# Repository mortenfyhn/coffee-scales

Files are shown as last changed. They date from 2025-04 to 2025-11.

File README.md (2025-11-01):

# coffee-scales



Kitchen scales, built for drip coffee brewing:

* 0.1 gram precision
* Very quick response
* Very quick tare
* Auto-starting brew timer
* Auto-off after 5 minutes

Current prototype looks something like this:

A PCB prototype in action

## Firmware

Setup:

1. [Install PlatformIO Core and shell commands](https://docs.platformio.org/en/latest/core/installation/index.html)
2. [Install Just](https://just.systems/man/en/packages.html)

Usage:

```sh
cd firmware
just --list
```

to list all recipes.

## Hardware

* Adafruit Feather 328P
* Load cell: 1 kg straight bar
* HX711 load cell amplifier
* Two 4-digit 7-segment displays with TM1637 drivers
* LiPo battery (1200 mAh)
* Push button for taring

Connection diagram

## Development and debugging

Log raw data to CSV with the logging recipe. Then process the data with `firmware/logs/process.m`. Look at the processed CSV in e.g. PlotJuggler.

Here's the state diagram:



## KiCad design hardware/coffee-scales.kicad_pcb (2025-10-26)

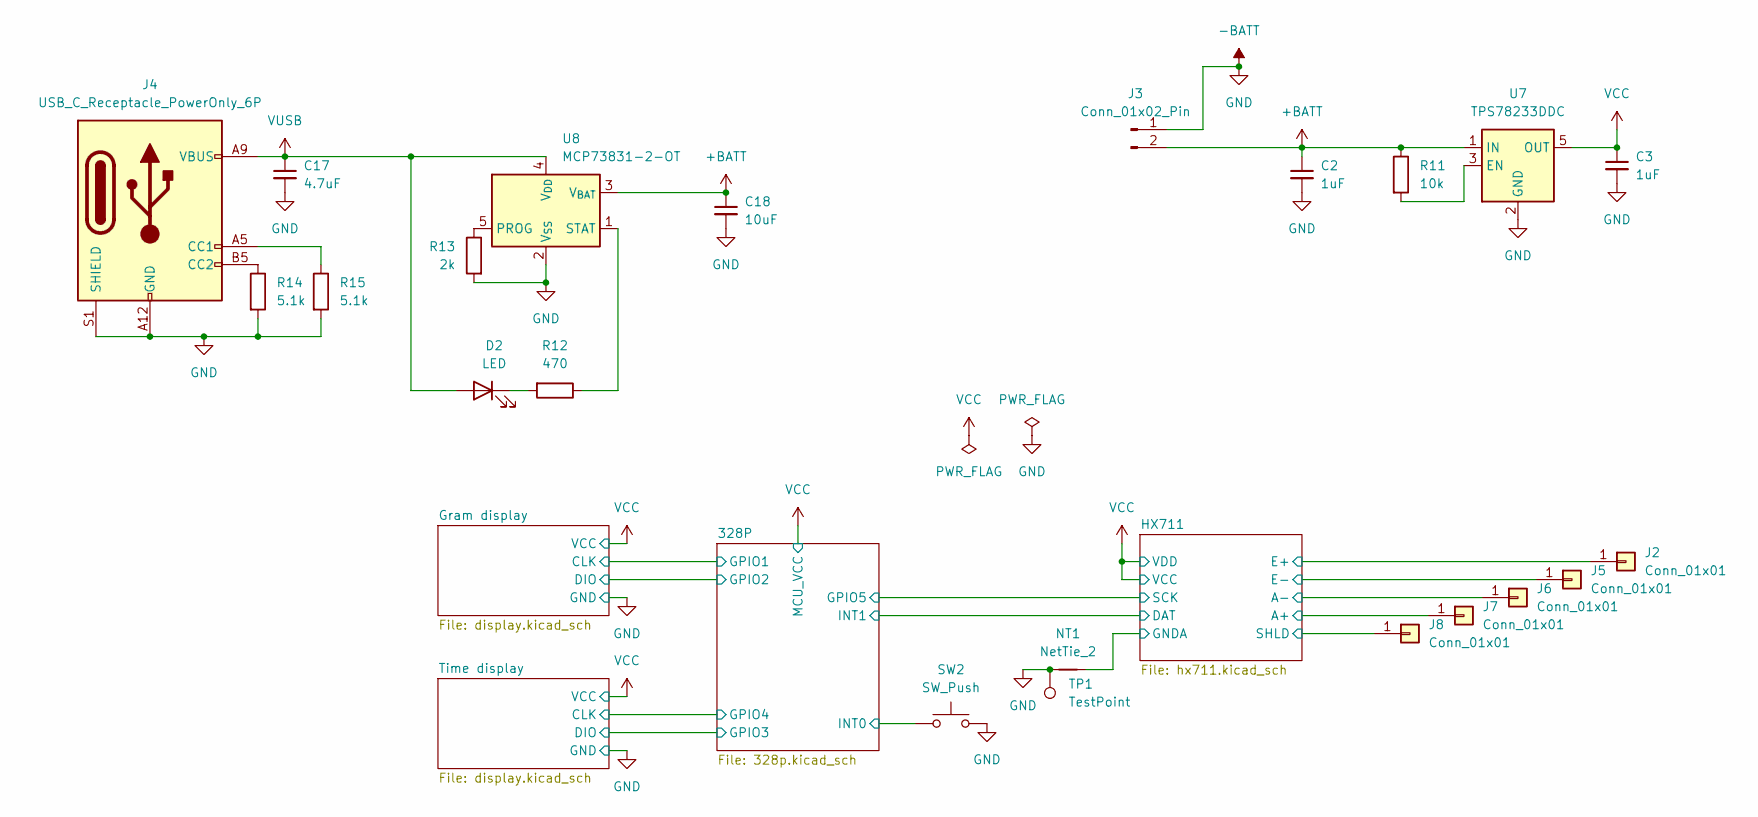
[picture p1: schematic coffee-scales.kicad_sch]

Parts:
C2, C3: 1uF; C_0603_1608Metric
C17: 4.7uF; C_0805_2012Metric
C18: 10uF; C_0805_2012Metric
D2: LED; LED_0805_2012Metric
J2, J5, J6, J7, J8: Conn_01x01; TestPoint_Pad_D1.5mm
J3: Conn_01x02_Pin; JST_PH_S2B-PH-SM4-TB_1x02-1MP_P2.00mm_Horizontal
J4: USB_C_Receptacle_PowerOnly_6P; USB_C_Receptacle_GCT_USB4125-xx-x-0190_6P_TopMnt_Horizontal
NT1: NetTie_2; NetTie-2_SMD_Pad0.5mm
R11: 10k; R_0603_1608Metric
R12: 470; R_0603_1608Metric
R13: 2k; LED_0603_1608Metric
R14, R15: 5.1k; R_0603_1608Metric
SW2: SW_Push; SW_PUSH-12mm
TP1: TestPoint; TestPoint_THTPad_D1.0mm_Drill0.5mm
U7: TPS78233DDC; SOT-23-5
U8: MCP73831-2-OT; SOT-23-5

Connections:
+BATT: C2.1, C18.1, J3.2, R11.1, U7.1 (IN), U8.3 (V_{BAT})
-BATT: C2.2, C3.2, C17.2, C18.2, J3.1, J4.A12 (GND), J4.B12 (GND), J4.S1 (SHIELD), NT1.2, R13.2, R14.2, R15.2, SW2.2, TP1.1, U7.2 (GND), U7.4 (GND), U8.2 (V_{SS}); also elsewhere on the board
/328P/INT0: SW2.1; also elsewhere on the board
/HX711/A+: J7.1; also elsewhere on the board
/HX711/A-: J6.1; also elsewhere on the board
/HX711/E+: J2.1; also elsewhere on the board
GNDA: J5.1, J8.1, NT1.1; also elsewhere on the board
unnamed: D2.1 (K), R12.2
unnamed: J4.A5 (CC1), R15.1
unnamed: J4.B5 (CC2), R14.1
unnamed: R11.2, U7.3 (EN)
unnamed: R13.1, U8.5 (PROG)
unnamed: R12.1, U8.1 (STAT)
VCC: C3.1, U7.5 (OUT); also elsewhere on the board
VUSB: C17.1, D2.2 (A), J4.A9 (VBUS), J4.B9 (VBUS), U8.4 (V_{DD})

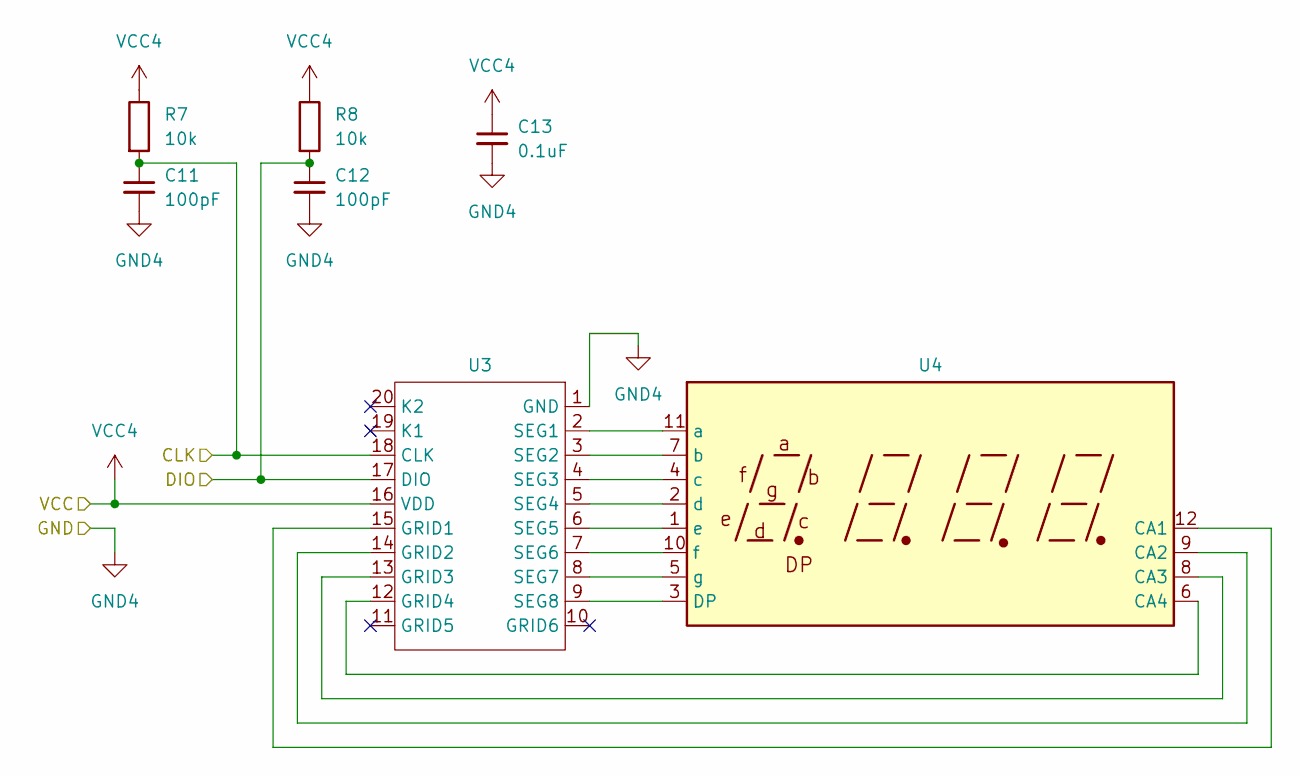
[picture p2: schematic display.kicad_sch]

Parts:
C11, C12: 100pF; C_0603_1608Metric
C13: 0.1uF; C_0603_1608Metric
R7, R8: 10k; R_0603_1608Metric
U3: SOP-20_7.5x12.8mm_P1.27mm_3d
U4: 7_segment

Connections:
-BATT: C11.2, C12.2, C13.2, U3.1 (GND); also elsewhere on the board
/328P/GPIO1: C11.1, R7.2, U3.18 (CLK); also elsewhere on the board
/328P/GPIO2: C12.1, R8.2, U3.17 (DIO); also elsewhere on the board
unnamed: U3.15 (GRID1), U4.12 (CA1)
unnamed: U3.14 (GRID2), U4.9 (CA2)
unnamed: U3.13 (GRID3), U4.8 (CA3)
unnamed: U3.12 (GRID4), U4.6 (CA4)
unnamed: U3.2 (SEG1), U4.11 (a)
unnamed: U3.3 (SEG2), U4.7 (b)
unnamed: U3.4 (SEG3), U4.4 (c)
unnamed: U3.5 (SEG4), U4.2 (d)
unnamed: U3.6 (SEG5), U4.1 (e)
unnamed: U3.7 (SEG6), U4.10 (f)
unnamed: U3.8 (SEG7), U4.5 (g)
unnamed: U3.9 (SEG8), U4.3 (DP)
VCC: C13.1, R7.1, R8.1, U3.16 (VDD); also elsewhere on the board

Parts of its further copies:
C14, C15: 100pF; C_0603_1608Metric
C16: 0.1uF; C_0603_1608Metric
R9, R10: 10k; R_0603_1608Metric
U5: SOP-20_7.5x12.8mm_P1.27mm_3d
U6: 7_segment

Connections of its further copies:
-BATT: C14.2, C15.2, C16.2, U5.1 (GND); also elsewhere on the board
/328P/GPIO3: C14.1, R10.2, U5.17 (DIO); also elsewhere on the board
/328P/GPIO4: C15.1, R9.2, U5.18 (CLK); also elsewhere on the board
unnamed: U5.15 (GRID1), U6.12 (CA1)
unnamed: U5.14 (GRID2), U6.9 (CA2)
unnamed: U5.13 (GRID3), U6.8 (CA3)
unnamed: U5.12 (GRID4), U6.6 (CA4)
unnamed: U5.2 (SEG1), U6.11 (a)
unnamed: U5.3 (SEG2), U6.7 (b)
unnamed: U5.4 (SEG3), U6.4 (c)
unnamed: U5.5 (SEG4), U6.2 (d)
unnamed: U5.6 (SEG5), U6.1 (e)
unnamed: U5.7 (SEG6), U6.10 (f)
unnamed: U5.8 (SEG7), U6.5 (g)
unnamed: U5.9 (SEG8), U6.3 (DP)
VCC: C16.1, R9.1, R10.1, U5.16 (VDD); also elsewhere on the board

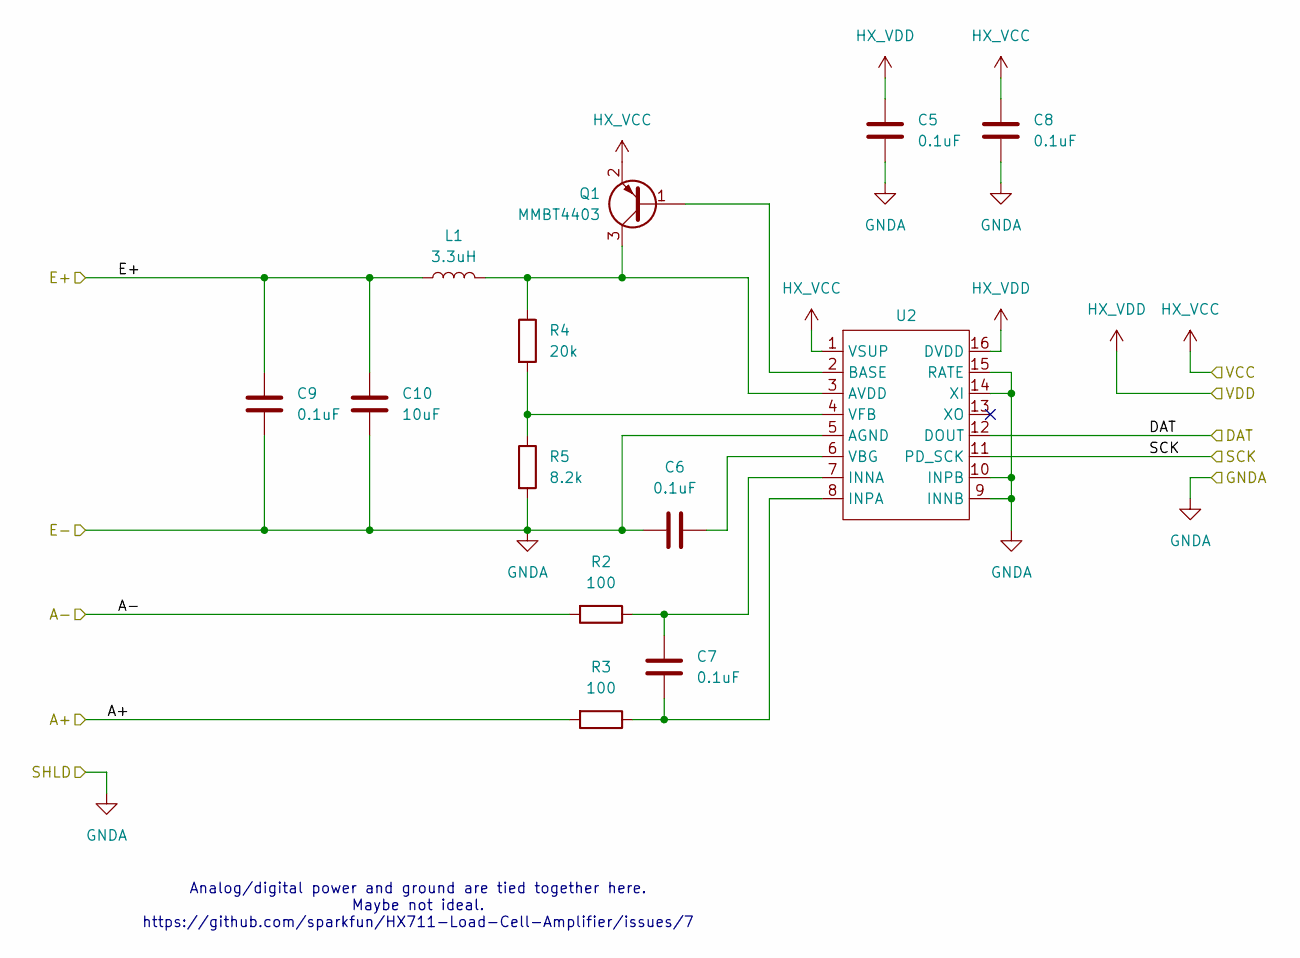
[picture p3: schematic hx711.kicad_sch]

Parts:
C5, C6, C7, C8, C9: 0.1uF; C_0603_1608Metric
C10: 10uF; C_1210_3225Metric
L1: 3.3uH; L_0805_2012Metric
Q1: MMBT4403; TSOT-23
R2, R3: 100; R_0603_1608Metric
R4: 20k; R_0603_1608Metric
R5: 8.2k; R_0603_1608Metric
U2: SOP-16_3.9x9.9mm_P1.27mm

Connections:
/HX711/A+: R3.2; also elsewhere on the board
/HX711/A-: R2.2; also elsewhere on the board
/HX711/DAT: U2.12 (DOUT); also elsewhere on the board
/HX711/E+: C9.1, C10.1, L1.1; also elsewhere on the board
/HX711/SCK: U2.11 (PD_SCK); also elsewhere on the board
GNDA: C5.2, C6.1, C8.2, C9.2, C10.2, R5.2, U2.5 (AGND), U2.9 (INNB), U2.10 (INPB), U2.14 (XI), U2.15 (RATE); also elsewhere on the board
unnamed: Q1.1 (B), U2.2 (BASE)
unnamed: L1.2, Q1.3 (C), R4.1, U2.3 (AVDD)
unnamed: C7.1, R2.1, U2.7 (INNA)
unnamed: C7.2, R3.1, U2.8 (INPA)
unnamed: C6.2, U2.6 (VBG)
unnamed: R4.2, R5.1, U2.4 (VFB)
VCC: C5.1, C8.1, Q1.2 (E), U2.1 (VSUP), U2.16 (DVDD); also elsewhere on the board

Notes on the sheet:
Analog/digital power and ground are tied together here. Maybe not ideal. https://github.com/sparkfun/HX711-Load-Cell-Amplifier/issues/7

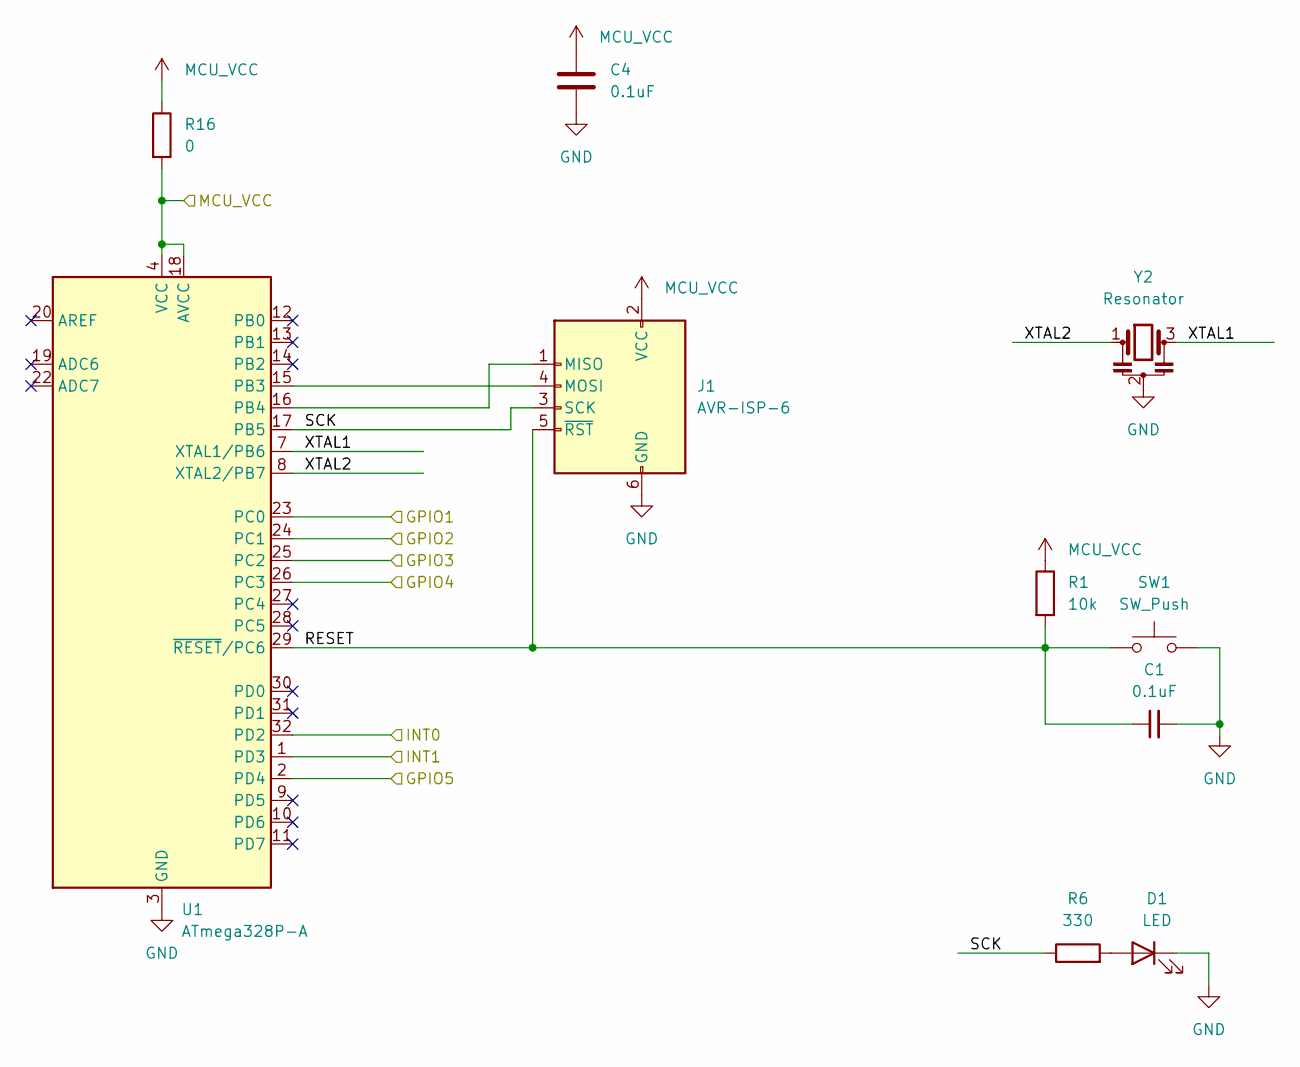
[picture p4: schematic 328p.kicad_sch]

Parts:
C1, C4: 0.1uF; C_0603_1608Metric
D1: LED; LED_0805_2012Metric
J1: AVR-ISP-6; PinHeader_2x03_P2.54mm_Horizontal
R1: 10k; R_0603_1608Metric
R6: 330; R_0603_1608Metric
R16: 0; R_1206_3216Metric_Pad1.30x1.75mm_HandSolder
SW1: SW_Push; SW_Push_1P1T_NO_CK_KMR2
U1: ATmega328P-A; TQFP-32_7x7mm_P0.8mm
Y2: Resonator; Resonator_SMD_Murata_CSTxExxV-3Pin_3.0x1.1mm

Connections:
-BATT: C1.2, C4.2, D1.1 (K), J1.6 (GND), SW1.2, U1.3 (GND), U1.5 (GND), U1.21 (GND), Y2.2; also elsewhere on the board
/328P/GPIO1: U1.23 (PC0); also elsewhere on the board
/328P/GPIO2: U1.24 (PC1); also elsewhere on the board
/328P/GPIO3: U1.25 (PC2); also elsewhere on the board
/328P/GPIO4: U1.26 (PC3); also elsewhere on the board
/328P/INT0: U1.32 (PD2); also elsewhere on the board
/328P/RESET: C1.1, J1.5 (~RST), R1.2, SW1.1, U1.29 (~RESET/PC6)
/328P/SCK: J1.3 (SCK), R6.1, U1.17 (PB5)
/328P/XTAL1: U1.7 (XTAL1/PB6), Y2.3
/328P/XTAL2: U1.8 (XTAL2/PB7), Y2.1
/HX711/DAT: U1.1 (PD3); also elsewhere on the board
/HX711/SCK: U1.2 (PD4); also elsewhere on the board
unnamed: D1.2 (A), R6.2
unnamed: J1.1 (MISO), U1.16 (PB4)
unnamed: J1.4 (MOSI), U1.15 (PB3)
VCC: C4.1, J1.2 (VCC), R1.1, R16.1, R16.2, U1.4 (VCC), U1.6 (VCC), U1.18 (AVCC); also elsewhere on the board

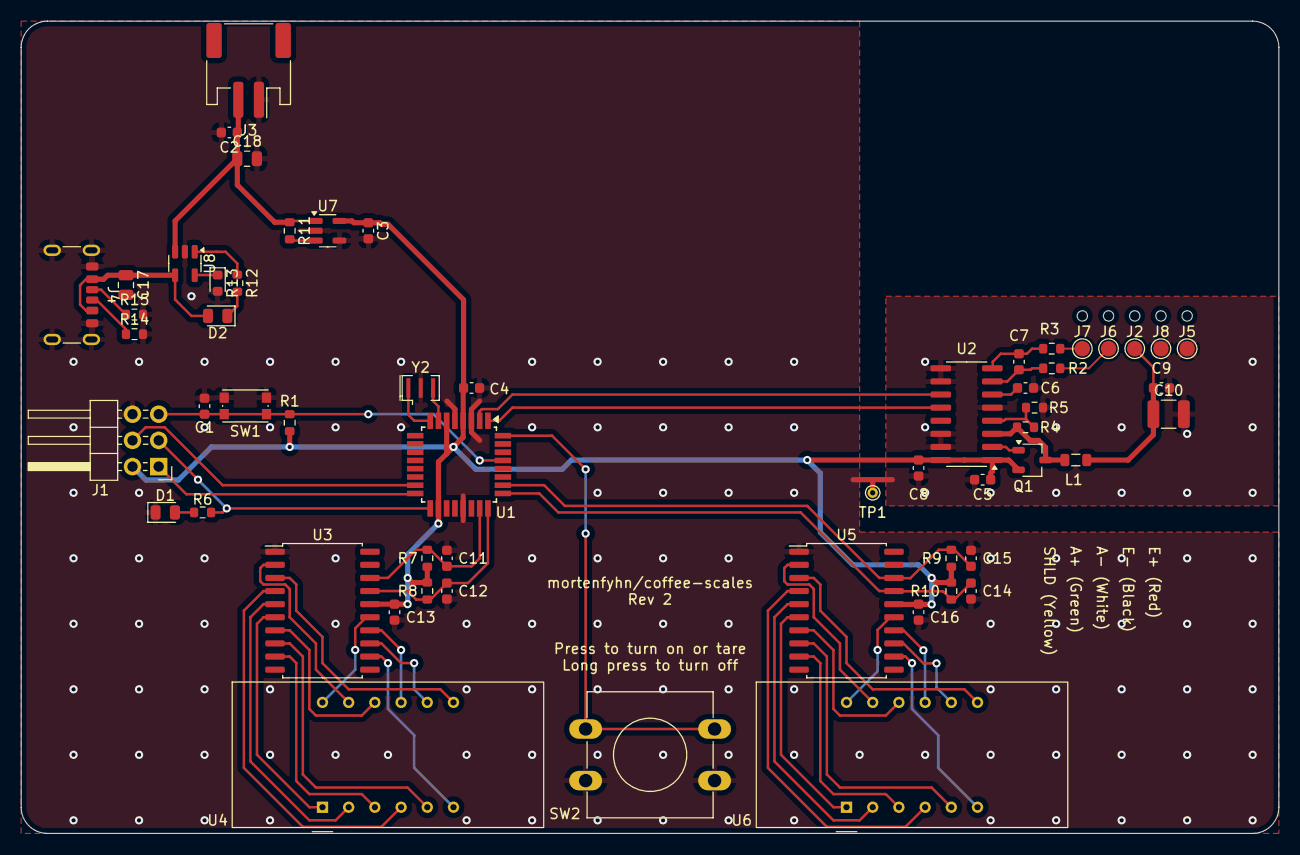
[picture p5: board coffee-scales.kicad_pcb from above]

Board: 2 copper layers, 121.9 x 78.7 mm, 58 parts (0 on the bottom side), 58 nets.

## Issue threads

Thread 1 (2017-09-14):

Add support for negative weight

mortenfyhn, 2017-09-14:
The scales cannot currently display negative numbers on the 7-segment display. Fix it.

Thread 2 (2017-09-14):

Reduce measurement jitter

mortenfyhn, 2017-09-14:
The measurement sometimes jitters between adjacent tenth of gram values. Need better measurement filtering to avoid this.

mortenfyhn, 2017-09-14:
Achieved using hysteresis (commit 2903dbe).

Closed 2017-09-14.

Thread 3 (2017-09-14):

Add tare button

mortenfyhn, 2017-09-14:
Add a physical tare button, and implement it in software. Should probably just be a simple momentary button. Even I can understand the circuit:

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
---
* [ ] Choose a button that fits and feels nice.
* [ ] Integrate it.

mortenfyhn, 2020-11-28:
Also do #14 as part of this.

mortenfyhn, 2023-05-01:
Closed by 229d202

Closed 2023-05-01.

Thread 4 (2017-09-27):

Question: What sort of load cell did you use for this project?

brianbowden, 2017-09-27:

mortenfyhn, 2017-09-28:
I use a cheap 1 kg load cell that came with an HX711 load cell amplifier breakout board, similar to this: https://i.imgur.com/7wJsbHm.jpg. Five dollars on eBay.

Closed 2017-09-28.

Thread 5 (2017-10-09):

Automatic display brightness

mortenfyhn, 2017-10-09:
I'll just use a photoresistor. Keep it simple. With the random ldr I have, I measure approx
* 1 ohm (raw 633) outside on a bright but overcast day (should give 100 % brightness)
* 2k ohm (raw 540) in a bright room (should give 100 % brightness)
* 10k (raw 350) ohm in a medium bright room (should probably give less than 100 % brightness)
* above 2M ohm (raw 36) in a really dark room with no lights on (should give minimum brightness)

So it seems that with a circuit like `[3v3]---[ldr]---[Vmeas]---[10K]---[gnd]` and the ldr I have, a good starting point is: max brightness above `Vmeas = 2.44 V (500 raw analog with Vref = 5v)` and minimum brightness below `Vmeas = 0.73 V (150 raw analog)`.

---
* [x] Get suitable photoresistor.
* [x] Figure out suitable fixed series resistor. --> 10k
* [ ] Test separately (write a small program that outputs 0-100 depending on ambient light).
* [ ] Integrate with everything else.

Closed 2020-10-31.

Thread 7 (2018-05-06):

Choose and order new computer

mortenfyhn, 2018-05-06:
Adafruit feathers seem nice because they have the charging circuit integrated:
* [Feather 328P](https://www.adafruit.com/product/3458): same mcu as the old arduino
* [Feather M0](https://www.adafruit.com/product/2772): more power and a bit more proto space
---
* [x] Decide which to order --> M0 lol
* [x] Order comp
* [x] Order battery

mortenfyhn, 2018-07-18:
Done!

Closed 2018-07-18.

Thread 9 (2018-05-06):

Make display modules

mortenfyhn, 2018-05-06:
The old display modules are too big. Gonna develop new ones that
* have a PCB that is the same height as the 7-segment itself,
* are the same size (0.56") or smaller, and
* probably use the HT16K33 instead of TM1637 (HT seems to require fewer external components).
---
* [ ] Make schematic.
* [ ] Make layout.
* [ ] Order from osh park or something.
* [ ] Order 7-segments.
* [x] Order HT16K33s (can get them [here](https://lcsc.com/product-detail/LED-Drivers_HT16K33_C87502.html))
* [ ] Assemble and verify.

Closed 2020-10-31.

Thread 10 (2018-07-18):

Don't reset timer when removing weight

mortenfyhn, 2018-07-18:

Closed 2018-07-20.

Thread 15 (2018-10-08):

Successive tare computation

mortenfyhn, 2018-10-08:
The current taring just reads a raw value _n_ times and sets the offset equal to the average of the readings. What if I instead take a single reading and set the offset repeatedly until for instance the change in offset is very small. Then taring a) might go faster and b) won't fail if it happens while the applied weight changes.

Closed 2020-10-31.

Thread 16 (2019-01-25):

Sometimes displays wrong weight

mortenfyhn, 2019-01-25:
Seems to happen after it's been used with a particularly heavy item. The weight starts to alternate between 1156 and 1565 at something like 3 Hz. The timer still runs fine.

Closed 2020-10-31.

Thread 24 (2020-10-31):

Filtering is broken

mortenfyhn, 2020-10-31:
The weight reading is very unstable.

mortenfyhn, 2020-11-01:
I printed the raw value going into the filter and the filtered value coming out, and they are the same:
```
-0.07 -0.07
0.28 0.28
1.18 1.18
1.56 1.56
1.53 1.56
1.13 1.13
2.10 2.10
2.95 2.95
1.96 1.96
1.11 1.11
```

mortenfyhn, 2020-11-01:
Seems to be caused by the filter always reporting "not in steady state", in which case it just returns the most recent value. I think the raw signal from the load cell amplifier is noisier than it used to be, for whatever reason.

mortenfyhn, 2020-11-01:
"Fixed" by using another HX711 breakout board. Maybe the bad one used 80 Hz higher noise sampling, and the good one 10 Hz, I think I read about that in the datasheet.

Closed 2020-11-01.

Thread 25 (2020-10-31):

Refactor gramsDisplay with tests

mortenfyhn, 2020-10-31:
A good opportunity to try out doctest

* [x] Get any test example running
* [x] Share dependency specification

mortenfyhn, 2020-11-02:
Possible to do this?

* Convert float to string, with exactly one decimal place
* if 4 chars or less (excluding decimal separator dot)
  * return result
* try convert with no decimal place
* if 4 chars or less
  * return result
* print error

mortenfyhn, 2020-11-28:
Done! 6146b00

Closed 2020-11-28.

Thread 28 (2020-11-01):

Set up static analysis

mortenfyhn, 2020-11-01:
Clang tidy probably.

* [ ] Run and fix current clang tidy errors.
* [ ] Integrate with CI.

Closed 2023-04-30.

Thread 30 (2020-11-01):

Design new PCB

mortenfyhn, 2020-11-01:
Gotta decide what to include and what to skip.

sindrehan, 2020-11-20:
Let me know if you want a review of/help with the PCB. Are you using KiCad?

mortenfyhn, 2020-11-20:
That'd be great! @yttersian is helping out with PCB design, maybe we can all collaborate? I don't remember what he suggested using. @Slattsveen has also offered to help with making an enclosure / machining.

Roughly, the plan for the first pcb revision is

* Still use the full arduino nano 328, and just solder its pin headers to the pcb.
* Get rid of the seven segment display breakouts, get the TM1637 + display circuits onto our board
* Add batteries + battery circuit (rechargeable, or disposable if they last long enough)
* Add a tare button
* Either create a drop-in slot for the HX711 breakout, or re-implement that directly on the board

Closed 2023-04-30.

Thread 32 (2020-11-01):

Consistent 0.0 after boot

mortenfyhn, 2020-11-01:
Seems that the HX711 outputs slightly wrong data first. Maybe we can adjust the tare function to wait for it to settle.

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

mortenfyhn, 2020-11-02:
Maybe we can cheat by having a small deadband around zero.

mortenfyhn, 2020-11-17:
Kinda works now.

mortenfyhn, 2023-05-11:
Plan:

* [ ] Get a log of data from a typical brew
* [ ] Then try different filtering techniques until flat parts are completely flat and changing parts change with minimal delay
* [ ] Discretize the output to 0.1 g intervals to check jitter

mortenfyhn, 2023-05-31:
Right now it's __almost__ consistent 0.0 after tare. The fix must be to tare based on an averaged value instead of based on just one reading.

mortenfyhn, 2023-05-31:
Took another startup log, and it seems the first 5-ish measurements (0.3 ish seconds) are off, before it settles.

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

Closed 2023-12-10.

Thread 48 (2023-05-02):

Mount everything on perfboard

mortenfyhn, 2023-05-02:
* [x] Need to get a switch (a nice toggle)
* [ ] Figure out layout
* [ ] Need larger board?
* [ ] Solder it up!

mortenfyhn, 2023-05-03:
https://www.taydaelectronics.com/sub-mini-toggle-switch-2m-series-spst-off-on.html

mortenfyhn, 2023-05-03:
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

Closed 2023-12-15.

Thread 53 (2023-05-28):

Log raw data for filter testing

mortenfyhn, 2023-05-28:

mortenfyhn, 2023-05-28:
Here is some:

[log.txt](https://github.com/mortenfyhn/coffee-scales/files/11584877/log.txt)

This is from actually brewing a cup of coffee:

* 12 g coffee
* 200 g water
* Using Hoffman's new V60 method: Pour 1/5th of the water at 0:00, 0:45, 1:10, 1:30, and 1:50.
* Swirl after first pour and after final pour.
* Done after roughly 3:30 (220k in the log)
* Left to sit until 5:00

The log format is just `MILLIS DATA` (space separated) with milliseconds since device boot, and DATA being raw data from the load cell amplifier. The input to the filter is (DATA - offset) / scale, where the scale is 1874.f and the offset is whatever makes it zero in the beginning.

Closed 2023-05-28.

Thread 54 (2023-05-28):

Design a better filter

mortenfyhn, 2023-05-28:
Use the logged data I have.

Spec / goal:
* Zero jitter during steady state
* Very quick response when adding weight
* No overshoot

Maybe bias estimation? In the log data, after finishing the pour, the data falls from 200.45 to 198.98 over approx 90 seconds. But maybe that's just evaporation!?

* [ ] Take another log, maybe 10 minutes, with nothing on the scales.

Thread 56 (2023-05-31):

Low battery indicator

mortenfyhn, 2023-05-31:

mortenfyhn, 2023-05-31:
Fixed!

Closed 2023-05-31.

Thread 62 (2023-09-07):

Make it legible in sunlight

mortenfyhn, 2023-09-07:
The Acaia Pearl has it so why not I?

mortenfyhn, 2023-12-10:
Looks like just wiring the displays to VBAT instead of 3V3 helps a lot if the battery is fully charged. So that's something.

mortenfyhn, 2023-12-15:
Sort of fixed by hooking up the display's vcc line to VBAT instead of the feather's 3v3 output, which means they get something like 3.6 to 4.2 volts, depending on battery charge.

Closed 2023-12-15.

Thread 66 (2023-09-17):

Proper solution for on/off

mortenfyhn, 2023-09-17:
Can I wake it with the tare button, and have it auto-off?

mortenfyhn, 2023-12-15:
I've got it.

* AVR deep sleep after 5 min inactivity
* Wake on interrupt (the tare button)
* Physically cut of the power leds underneath the display modules
* Set the HX711 to power down before entering sleep mode

Fixed by a7e02a1

Closed 2023-12-15.

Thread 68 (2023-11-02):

Flash low batt lamp instead of just turn it on

mortenfyhn, 2023-11-02:
And actually test it...

mortenfyhn, 2023-12-09:
It seems to work! I didn't measure the voltages, but it turned red recently and charging it overnight made it no longer red : )

Closed 2023-12-15.

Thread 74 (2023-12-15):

Minimize power consumption

mortenfyhn, 2023-12-15:
The entire device (measured on battery input at 4.1 V):

* Active: 50-60 mA
* Sleep: 0.5 mA @ 4.1 V = 2.05 mW

The load cell + amplifier (measured on 3.3 V line):

* Active: 10 mA
* Sleep: 0.0 uA

The displays (measured on battery line at 4.1 V):

* Active: 50 mA
* Sleep: 190 uA @ 4.1 V = 0.78 mW

The push button uses a small amount of power when pressed and nothing when not pressed.

So where is the remaining 1.27 mW going??

Standby: 0.5 mA gives around 100 days.
Usage: 50 mA gives around 24 hours.
So if I use it, say, twice a day, 5 min brew + 5 min timeout each time, that's 20 minutes usage per day + 1420 minutes standby. That's 16.7 mAh (usage) + 11.8 mAh (standby) = 28.5 mAh -> 42 days, assuming 1200 mAh battery.
Very back of the envelope.

mortenfyhn, 2023-12-31:
* [ ] Do the displays use more power in standby because they're hooked up to the battery line instead of the 3v3 line?

mortenfyhn, 2024-01-03:
The TM1637 driver has a parameter `bool on`. I wonder if the power consumption is changed by this, when all segments are off:

https://github.com/avishorp/TM1637/blob/82214be06742bf187fab4f29aaabb64c289eaae0/TM1637Display.h#L49-L51

mortenfyhn, 2024-12-15:
Maybe switch to an ATtiny1614 eventually

mortenfyhn, 2024-12-29:
Some profiling of the active state loop of today's version (235c0ac):

| task | description            | approx. duration (us) |
|------|------------------------|-|
| 1    | check for button press | 8 |
| 2    | wait for hx711 ready   | (irrelevant) |
| 3    | read from hx711        | 800 |
| 4    | compute grams [1]      | 80 |
| 5    | add value to filter    | 80 |
| 6    | get filtered value     | 1000 |
| 7    | compute hysteresis     | 60 |
| 8    | format scale segments  | 450 |
| 9    | set scale segments     | **23 150** |
| 10   | update timer display   | **34 250** |
| 11   | check for steady state | 700 |
| 12   | check activity timeout | 8 |

[1]:

https://github.com/mortenfyhn/coffee-scales/blob/235c0ac4d8fc71c11c5e866e6baab060c1ca74b6/firmware/src/main.cpp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

mortenfyhn, 2024-12-29:
However with a different 7segment library:

| task | description            | approx. duration (us) |
|------|------------------------|-|
| 1    | check for button press | 8 |
| 2    | wait for hx711 ready   | - |
| 3    | read from hx711        | 746 |
| 4    | compute grams          | 76 |
| 5    | add value to filter    | 70 |
| 6    | get filtered value     | 963 |
| 7    | compute hysteresis     | 53 |
| 8    | format scale segments  | 481 |
| 9    | set scale segments     | 1015 |
| 10   | update timer display   | 1503 |
| 11   | check for steady state | 700 |
| 12   | check activity timeout | 14 |

mortenfyhn, 2024-12-29:
So that means we for each 100 ms iteration (HX711 is configured for 10 Hz output), we work for 5-6 ms, and then do nothing (busy loop) for the remainder.

Note that the above is all with `-Os`.

**Next:**

* [ ] Actually implement sleeping and interrupt wake for when the HX711 is ready
* [ ] Try to squeeze even more speed improvements?

mortenfyhn, 2024-12-29:
Anyway come back to this after standalone MCU PCB without arduino board.

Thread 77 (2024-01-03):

Disable or fix low battery light

mortenfyhn, 2024-01-03:
It seems to be poorly calibrated, and if I charge it without power cycling it won't turn off when the battery is full after charging.

Closed 2024-01-03.

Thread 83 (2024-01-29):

Long press to shut down

mortenfyhn, 2024-01-29:
I've long resisted having another shutdown button or method than just "wait for it to time out".

But a long press might be good. Then anyone who wants to be able to immediately shut down can, without this affecting the UI/UX for everyone else.

mortenfyhn, 2024-02-23:
* same logic as today's tare?
* start taring immediately even if doing a long press
* check the button class state for each iteration (no interrupt here)
* class logic can then determine if button has been pressed at every checkpoint for the last X duration

mortenfyhn, 2024-04-08:
I have something that kind of works now. But:

* [ ] after the button is held down and the scales sleep, the interrupt must become a no-op for a little while

otherwise letting go of the button very easily wakes it right up again, because of bouncing.

Closed 2024-05-12.

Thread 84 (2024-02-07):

Manual sleep before HX711 read?

mortenfyhn, 2024-02-07:
If the read is a busy loop, maybe that's wasting energy and I instead can sleep until it's ready.

mortenfyhn, 2024-05-12:
It does seem to be a busy loop, the HX711 driver just does "while not ready, delay(0)".

I should instead try to estimate when it will be ready and do some kind of proper low power sleep until then.

I should also consider just hooking up an interrupt to the DOUT pin, which is what "is ready" actually checks: When DOUT goes low, it means data is ready for reading.

And I should do some timing again to see which parts of the program take how much time.

And then consider optimizing the rest of the code.

mortenfyhn, 2024-12-29:
Subset of #74

Closed 2024-12-29.

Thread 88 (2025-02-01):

Long press does not always work

mortenfyhn, 2025-02-01:
Sometimes it just randomly does not work (pressing the button does not cause sleep). And during taring it never works. It should always work.

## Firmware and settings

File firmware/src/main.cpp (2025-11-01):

#include "button.h"
#include "config.h"
#include "serial.h"
#include <Arduino.h>
#include <Display.h>
#include <Formatter.h>
#include <HX711.h>
#include <Hysteresis.h>
#include <SmoothingFilter.h>
#include <TimerDisplay.h>
#include <avr/sleep.h>
#include <stdint.h>

enum class State
{
    taring,
    ready,
    brewing,
    dim,
    sleep,
} state_ = State::taring;

auto load_cell_ = HX711{};
auto filter_ = SmoothingFilter{config::filter_size};
auto hysteresis_ = Hysteresis{config::hysteresis_size};
auto weight_display_ =
    Display{pins::scale_display_clk, pins::scale_display_dio};
auto timer_display_ =
    TimerDisplay{pins::timer_display_clk, pins::timer_display_dio};
auto button_ = Button{pins::tare_button};
uint32_t last_activity_time_ms_ = 0;
float bias_ = 0.f;
float prev_filtered_ = 0.f;
float bias_compensated_ = 0.f;

float read_battery_voltage()
{
    return config::battery_scaling * analogRead(pins::battery_voltage);
}

void read_load_cell_and_update_filter()
{
    const int32_t raw_value = load_cell_.read();
    log(raw_value);
    const float weight_in_grams_raw =
        (raw_value - load_cell_.get_offset()) / config::division_factor;
    filter_.addValue(weight_in_grams_raw);

    const auto curr_filtered = filter_.getValue();
    if (filter_.hasSteadyState())
    {
        bias_ += curr_filtered - prev_filtered_;
    }
    bias_compensated_ = curr_filtered - bias_;
    prev_filtered_ = curr_filtered;
}

void tare()
{
    const int32_t new_offset =
        load_cell_.get_offset() + filter_.getValue() * config::division_factor;
    load_cell_.set_offset(new_offset);
    hysteresis_.reset();

    bias_ = 0.f;
    prev_filtered_ = 0.f;
    bias_compensated_ = 0.f;
}

void attachTareButtonInterrupt()
{
    attachInterrupt(
        digitalPinToInterrupt(pins::tare_button),
        [] { button_.interrupt_handler(); }, FALLING);
}

void detachTareButtonInterrupt()
{
    detachInterrupt(digitalPinToInterrupt(pins::tare_button));
}

//--- TRANSITIONS --------------------------------------------------------------

[[nodiscard]] State transitionToTaring()
{
    debug("-> taring");

    weight_display_.setBrightnessMax();
    timer_display_.setBrightnessMax();

    timer_display_.stop();
    last_activity_time_ms_ = millis();

    return State::taring;
}

[[nodiscard]] State transitionToReady()
{
    debug(" -> ready");

    weight_display_.setBrightnessMax();
    timer_display_.setBrightnessMax();

    return State::ready;
}

[[nodiscard]] State transitionToBrewing()
{
    debug("  -> brewing");

    weight_display_.setBrightnessMax();
    timer_display_.setBrightnessMax();

    timer_display_.start();

    return State::brewing;
}

[[nodiscard]] State transitionToDim()
{
    debug("   -> dim");

    weight_display_.setBrightnessDim();
    timer_display_.setBrightnessDim();

    return State::dim;
}

[[nodiscard]] State transitionToSleep()
{
    debug("    -> sleep");

    return State::sleep;
}

//--- STATES -------------------------------------------------------------------

[[nodiscard]] State taring()
{
    // I do this to clear any pending "should tares".
    // TODO: Figure out if needed, if not remove, if yes refactor.
    button_.is_pressed();

    // Placing this check early makes taring instant when the filter is already
    // stable, without wasting time on showing the "wait for taring" line.
    if (filter_.hasSteadyState())
    {
        tare();
        return transitionToReady();
    }

    weight_display_.showLine();

    read_load_cell_and_update_filter();

    return State::taring;
}

[[nodiscard]] State ready()
{
    if (button_.is_pressed())
    {
        debug("should tare");
        return transitionToTaring();
    }

    read_load_cell_and_update_filter();

    const float weight_in_grams = hysteresis_.compute(bias_compensated_);
    weight_display_.setSegments(Formatter::to_segments(weight_in_grams).get());

    if (!filter_.hasSteadyState())
    {
        last_activity_time_ms_ = millis();
    }

    if (weight_in_grams > 1.f)
    {
        return transitionToBrewing();
    }

    if (millis() - last_activity_time_ms_ > config::timeout_dim_ms)
    {
        return transitionToDim();
    }

    return State::ready;
}

[[nodiscard]] State brewing()
{
    if (button_.is_pressed())
    {
        debug("should tare");
        return transitionToTaring();
    }

    read_load_cell_and_update_filter();

    const float weight_in_grams = hysteresis_.compute(bias_compensated_);
    weight_display_.setSegments(Formatter::to_segments(weight_in_grams).get());
    timer_display_.update();

    if (!filter_.hasSteadyState())
    {
        last_activity_time_ms_ = millis();
    }

    if (millis() - last_activity_time_ms_ > config::timeout_dim_ms)
    {
        return transitionToDim();
    }

    return State::brewing;
}

[[nodiscard]] State dim()
{
    if (button_.is_pressed())
    {
        debug("should tare");
        return transitionToTaring();
    }

    read_load_cell_and_update_filter();

    const float weight_in_grams = hysteresis_.compute(bias_compensated_);

    weight_display_.setSegments(Formatter::to_segments(weight_in_grams).get());
    timer_display_.update();

    // todo maybe do this at the beginning?

    if (!filter_.hasSteadyState())
    {
        return transitionToBrewing();
    }

#ifndef LOGGING  // Don't sleep when logging
    if (millis() - last_activity_time_ms_ > config::timeout_sleep_ms)
    {
        return transitionToSleep();
    }
#endif

    return State::dim;
}

[[nodiscard]] State sleep()
{
    debug("sleep");

    weight_display_.clear();
    timer_display_.stop();
    filter_.clear();
    load_cell_.power_down();

    // Turn off red indicator LED that I stupidly tied the scale display's DIO pin to...
    digitalWrite(13, LOW);

    // When sleep mode is triggered by a long press, we must disable the
    // interrupt for a moment, so that letting go of the button doesn't trigger
    // the ISR and wake the device.
    detachTareButtonInterrupt();
    delay(1000ul);
    attachTareButtonInterrupt();

    sleep_mode();

    load_cell_.power_up();

    return transitionToTaring();
}

//--- SETUP/LOOP ---------------------------------------------------------------

void setup()
{
    serial_setup();
    debug("setup");

    // Configure button
    pinMode(pins::tare_button, INPUT_PULLUP);
    attachTareButtonInterrupt();

    // Enable power-down sleep
    set_sleep_mode(SLEEP_MODE_PWR_DOWN);
    sleep_enable();

    // Set up the load cell
    load_cell_.begin(pins::loadcell_dt, pins::loadcell_sck);
    load_cell_.set_scale(config::division_factor);

    // Print battery voltage
    auto buf = Buffer::buffer<char>{5};
    const auto battery_voltage_mV =
        static_cast<uint32_t>(read_battery_voltage() * 1000);
    snprintf(buf.data(), 5, "%lu", battery_voltage_mV);
    for (auto i = 0; i < 5; ++i)
        buf.data()[i] = weight_display_.encode(buf.data()[i]);
    buf.data()[0] |= 0b10000000;  // Add decimal dot
    weight_display_.printRaw(buf.data());

    delay(1000ul);

    state_ = transitionToTaring();
}

void loop()
{
    // debug("loop");

    if (button_.is_long_pressed())
    {
        state_ = transitionToSleep();
    }

    switch (state_)
    {
    case State::taring:
        state_ = taring();
        break;

    case State::ready:
        state_ = ready();
        break;

    case State::brewing:
        state_ = brewing();
        break;

    case State::dim:
        state_ = dim();
        break;

    case State::sleep:
        state_ = sleep();
        break;
    }
}

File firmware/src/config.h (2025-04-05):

#pragma once

#include <Arduino.h>  // uint8_t, A1

namespace pins
{
constexpr uint8_t loadcell_dt = SCL;
constexpr uint8_t loadcell_sck = SDA;
constexpr uint8_t timer_display_clk = 7;
constexpr uint8_t timer_display_dio = MISO;
constexpr uint8_t scale_display_clk = MOSI;
constexpr uint8_t scale_display_dio = SCK;
constexpr uint8_t tare_button = 2;  // Must be interrupt pin!
constexpr uint8_t battery_voltage = A6;
}  // namespace pins

namespace config
{
// To calibrate the division factor:
//   division factor = old division factor * measured / true
// where 'measured' and 'true' are the measured and true weights of an item.
constexpr float division_factor = 1540.32;
constexpr uint8_t num_tare_samples = 10;
constexpr uint8_t filter_size = 10;
constexpr float hysteresis_size = 0.1;
constexpr float battery_scaling = 2.0 * 3.3 / 1024.0;
constexpr uint32_t tare_interval_ms = 1000;
constexpr uint32_t timeout_dim_ms = 1 * 60 * 1000l;    // 1 min
constexpr uint32_t timeout_sleep_ms = 5 * 60 * 1000l;  // 5 min
}  // namespace config

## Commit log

2017-03-16 Add Arduino sketch
2017-08-29 Create object for timer display
2017-08-29 Update pin numbers and load cell params
2017-08-29 Remove unnecessary filter initialization
2017-09-14 Write a class for measurement filtering
2017-09-14 Implement hysteresis
    This reduces measurement jitter.
2017-09-14 Use member consts for smoothing filter parameters
2017-10-03 Take filter parameters in constructor
2018-07-20 Keep timer on
    Turns out it's really annoying that the timer resets when I remove the weight
    from the scales. Fixes #10.
    [main.cpp]
2018-07-21 Add 500 ms delay on boot
    Fixes #11.
    [main.cpp]
2020-11-01 Add Sublime Text project file
    Autogenerated from
    The current working directory /home/morten/workspace/coffee-scales will be used for the project.
    The next files/directories have been created in /home/morten/workspace/coffee-scales
    include - Put project header files here
    lib - Put here project specific (private) libraries
    src - Put project source files here
    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
2020-11-01 Avoid printing -0.0
    Instead just print -0.1 as the first negative number.
2020-11-15 Update pin connections
2020-11-28 Add printf library submodule
2020-11-28 Make sure negative zero prints without minus
2020-11-29 Swap display lib
    Fix #39.
    [main.cpp]
2020-11-29 Set brightness
    Fix #40
    [main.cpp]
2020-11-29 Implement tare button
    Fix 41
    [main.cpp]
2021-05-09 CI: Pin PlatformIO to v1.5.0
2023-05-01 Revive the scales!
    I've
    * gotten everything working again on a breadboard
    * added the tare button
    * done some minor refactoring of the main file.
2023-05-29 Add some useful logs
    [brew.csv, steadystate.csv]
2023-05-29 Refactor tare button logic
2023-05-29 Hysteresis: Reset when taring
    This should help with hitting exact 0.0
    [main.cpp]
2023-05-30 Add log processing!
    [brew.csv, steadystate.csv]
2023-05-31 Use pin names as printed on board
2023-05-31 Add low battery warning
2023-05-31 Add startup log
    [startup.csv]
2023-09-01 Fix low batt lamp bug
    [main.cpp]
2023-09-01 Tare based on interrupt
    This makes the taring work even if you very quickly tap
    the button.
    Fix #57
    [main.cpp]
2023-11-07 Adjust scaling for new load cell
    The old one broke
    [main.cpp]
2023-12-10 Tare with averaged value
    Fix #63
    [main.cpp]
2023-12-10 Wait for steady state before taring
    Fix #70
    [main.cpp]
2023-12-10 Reliable taring on boot, also
    Fix #32
    [main.cpp]
2023-12-10 Fix taring timer bug
    [main.cpp]
2023-12-15 Display battery voltage at boot
2024-01-03 Disable low battery lamp
    Fix #77
    [main.cpp]
2024-01-03 Display battery percentage at boot
2024-01-03 Dim display after 1 min inactivity
    Fix 76
    [main.cpp]
2024-02-03 Rewrite everything as a state machine
    Fix #82
    [button.h, config.h, main.cpp]
2024-02-04 Fix taring logic
    In some cases it would stay dim after taring
    [main.cpp]
2024-05-12 Implement long press to sleep
    Fix #83
    [button.h, main.cpp]
2024-12-07 Move everything to a subdir
    [brew.csv, startup.csv, steadystate.csv]
2024-12-08 Add KiCad files
    [coffee-scales.kicad_pcb, coffee-scales.kicad_sch]
2024-12-08 Clean up schematic a bit
    [coffee-scales.kicad_sch]
2024-12-08 Update pin config to match PCB
2024-12-23 Wire button and HX711 DT to interrupt pins
    [coffee-scales.kicad_pcb, coffee-scales.kicad_sch]
2024-12-25 Big but pointless PCB update
    * Rounded corners
    * Components not so close to the edge
    * HX711 data pin on interrupt
    * Bigger vias/pads
    * Square first pad
    * Lots of stuff added to silkscreen
    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
    [coffee-scales.kicad_pcb, coffee-scales.kicad_sch]
2024-12-25 Remove unused battery header
2024-12-28 Update calibration
2024-12-28 Config pins back to current PCB
2024-12-29 Fix uncleared colon
    Workaround for this
    https://github.com/bremme/arduino-tm1637/pull/67
2024-12-29 Turn off red LED when sleeping
2025-10-26 Change prototype image from breadboard to PCB
    Updated image link to reflect PCB prototype.
2025-10-26 Add (unmodified) Sparkfun HX711 breakout schematic
    [coffee-scales.kicad_sch, hx711.kicad_sch]
2025-10-26 Integrate HX711 sub-schematic
    [coffee-scales.kicad_sch, hx711.kicad_sch]
2025-10-26 Finish HX711 integration
    [coffee-scales.kicad_pcb, coffee-scales.kicad_sch, hx711.kicad_sch]
2025-10-26 Route most of the 328 stuff
    [328p.kicad_sch, coffee-scales.kicad_pcb, coffee-scales.kicad_sch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]
2025-10-26 Create analog ground plane for HX711
    [coffee-scales.kicad_pcb, coffee-scales.kicad_sch, hx711.kicad_sch]
2025-10-26 Infinite schematic/PCB changes
    [328p.kicad_sch, coffee-scales.kicad_pcb, coffee-scales.kicad_sch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]
2025-10-26 Everything routed and checked, except power supply
    [coffee-scales.kicad_pcb]
2025-10-26 Keep hacking
    [328p.kicad_sch, coffee-scales.kicad_pcb, coffee-scales.kicad_sch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]
2025-10-26 Further PCB tweaks
    [328p.kicad_sch, coffee-scales.kicad_pcb, coffee-scales.kicad_sch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]
2025-11-01 Fix logging
    Fix #92
    [main.cpp]
2025-11-01 Update output printing
2025-11-22 Clean up logging
    [brew.csv, coldstart.csv, startup.csv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]
2026-10-24 Log loop inputs and outputs in the logging build
    Log one CSV row per loop iteration with time, raw sample, read wait time,
    button events, state and displayed weight. This is enough to replay a log
    on the host. Print integers only, since float formatting is slow on AVR.
2026-10-24 Capture logs without an interactive terminal
    pio device monitor fails without a TTY. Read the port with pyserial instead.
    Drop the Octave processing step, since process-log.m can't read the new
    log format. The host replay will replace it.
2026-10-24 Move the scale logic into a library that builds on the host
    The state machine and signal processing move from main.cpp to lib/Scale
    with no changes in behaviour. Scale uses the device through a Hardware
    interface, which main.cpp implements. Constants that don't depend on
    Arduino move to lib/Config, and pins to src/pins.h. The log row moves to
    lib/LogRow, so the host can read logs with the same struct.
2026-10-24 Replay logs on the host
    The replay program runs lib/Scale with the inputs from a log, and reports
    iterations where the state or displayed weight differ from the device. It
    prints the intermediate processing stages as CSV. Run it with just replay.
2026-10-24 Log the time of tare button presses
    Needed to measure the time from a press to the tared display.
2026-10-24 Add a recipe that captures without uploading
    Uploading powers up the HX711 before the capture starts. Capturing
    without an upload records the warm-up after a cold start.
2026-10-24 Check the scale's behaviour on recorded logs
    check-logs.py replays each log in firmware/logs/ and checks that the
    display shows the true weight on every stable plateau, and measures settle
    time, tare latency and timer start. It fails if a result is worse than in
    logs/baseline.json. Replace the old logs, which had no button events, with
    three new ones: tares, return to zero and a 6 minute hold.
2026-10-24 Add a cold start brew log to the checks
    Brews evaporate, so for brew*.csv the display may follow slow changes or
    hide them, but must stay between the start weight and the current weight.
    Skip the first 4 s of a plateau instead of 2 s, so the sloshing after a
    swirl isn't counted. Plateaus under 0.5 g count as zero, since warm-up
    drift can move them past 0.05 g.
2026-10-24 Check the display against zero and the last zero plateau
    A zero plateau must show 0.0, and a loaded plateau is measured from the
    reading at the end of the previous zero plateau. This counts the scale's
    zero drift as an error. A tare press starts a new plateau.
    Add a cold start log with a solid object on and off every 30 s.
2026-10-24 Show the nearest tenth and reset the bias at each step
    The hysteresis now keeps the shown tenth while the input is within
    0.07 g of it, and otherwise shows the nearest tenth. Before, it could
    latch up to 0.1 g away from the input.
    The bias now resets when the reading changes, and the jump to the
    average when the filter becomes steady is not counted as drift. Before,
    both carried an offset across steps.
    The timer starts on the value before rounding, as before.
    The cold-steps check fails until the zero point drift is tracked.
2026-10-25 Track the zero point when the reading becomes steady near zero
    When the filter becomes steady within 0.3 g of zero, the scale tares.
    This removes the zero point drift while the scale warms up, which the
    bias reset in the previous commit no longer hides.
    All zero plateaus in the logs now show 0.0. Loaded plateaus in the cold
    start log can be one tenth low, because the load cell creeps after a
    step and the display freezes before that.
2026-10-25 Allow brews to show any weight the plateau had so far
    After a pour, the weight falls by about 0.8 g/min. The display freezes
    when the reading becomes steady, a few seconds before the check measured
    the true weight, so correct values failed the check. The old firmware
    still fails it, because it carries an offset across pours.
    Add a full brew log with the new firmware.
